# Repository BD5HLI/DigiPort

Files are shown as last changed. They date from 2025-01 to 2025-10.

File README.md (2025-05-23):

# 简介

面向八重洲FT-891的FT8模式集成接口，内置一个2口的USB2.0 HUB和一个USB声卡，通过一个Type-C接口连接电脑或者手机，解决FT-891没有内置声卡的问题。

本项目采用了Digirig-Mobile项目（https://github.com/softcomplex/Digirig-Mobile ）的符号库、封装库和3D器件模型，参考了Digirig DR-891的原理图（https://digirig.net/digirig-dr-891-setup-manual/ ）设计，精简了几乎用不到的CM108B GPIO脚的PTT功能，保留了VOX-PTT功能。此外，本项目的被动器件（电阻、电容）均采用0402手焊封装，便于手工焊接。

本项目虽然面向FT-891设计，实际上可以仅使用USB声卡的功能，从而适用于绝大多数带有音频输入输出接口的电台，比如K5、K6手台，配合相应的软件可以实现SSTV、APRS等玩法。

# 电路板渲染图

电路板正面：

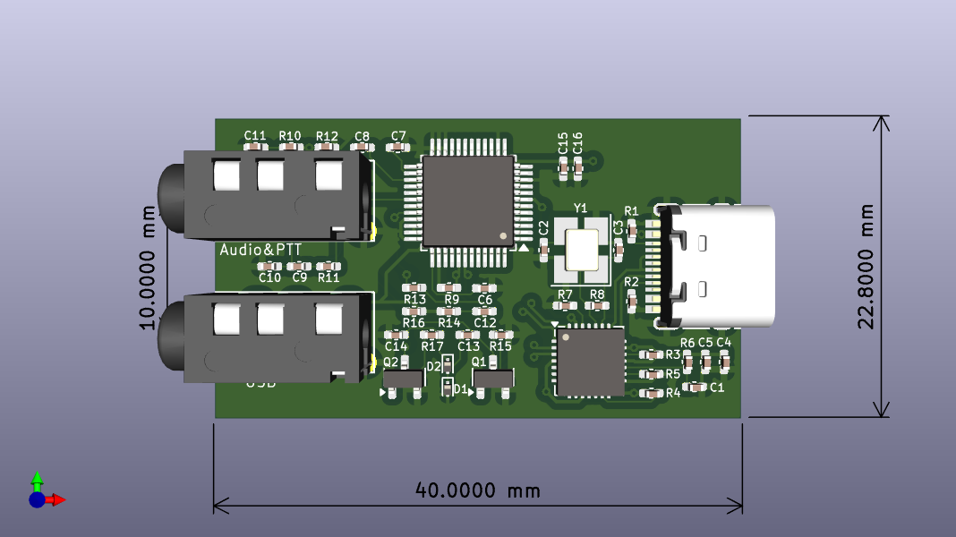
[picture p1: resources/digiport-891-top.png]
电路板正面


电路板反面：

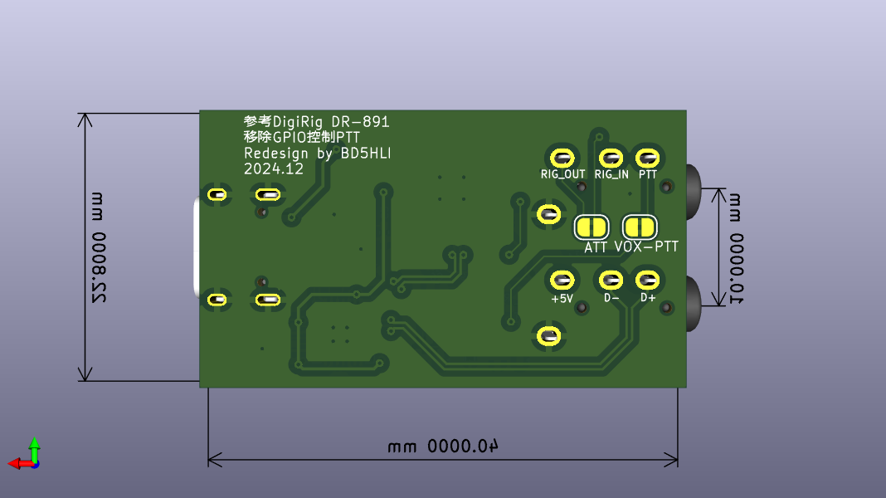
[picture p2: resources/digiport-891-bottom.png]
电路板反面


# 接口

DigiPort在电脑侧的接口为type c接口，可使用c to a或c to c数据线连接电脑或者手机；在电台侧的接口包括两个3.5mm的4芯TRRS接口，面向电路板器件面、type c接口在右侧时，左上的TRRS接口为音频/PTT接口，左下的TRRS接口为USB接口。

DigiPort的音频/PTT接口定义如下：  

```
   /\  
  |  |---------> 尖端   RIG_AFOUT 电台音频输出，接FT-891 DATA口的DATA OUT脚  
  |--|  
  |  |---------> 第一环 RIG_AFIN  电台音频输入，接FT-891 DATA口的DATA IN脚  
  |--|  
  |  |---------> 第二环 VOX_PTT   声控PTT，接FT-891 DATA口的PTT脚  
  |--|  
  |  |---------> 底部   GND       信号地，接FT-891 DATA口的GND脚  
__|  |__
|      |  
```

VOX_PTT信号用于没有USB串口的设备控制收发转换，控制源来自CM108B声卡的右声道，推荐采用1kHz或2kHz的单音作为VOX触发信号。

FT-891的DATA**插座**定义如下：

```
    /-----\      1脚：DATA IN  
   / 6 _ 5 \     2脚：GND  
  |4  |_|  3|    3脚：PTT  
   \ 2   1 /     4脚：SHIFT  
    \-----/      5脚：DATA OUT   
                 6脚：SQL   
```

DigiPort的电台侧USB接口定义如下：  

```
   /\  
  |  |---------> 尖端   +5V 电台USB口的+5V电源脚  
  |--|  
  |  |---------> 第一环 D-  电台USB口的D-脚  
  |--|  
  |  |---------> 第二环 D+  电台USB口的D+脚  
  |--|  
  |  |---------> 底部   GND 电台USB口的GND脚  
__|  |__  
|      |  
```

USB Type-B**插头**定义如下：

```
   /-+=+--+=+-\     1脚：+5V     
  /  |=|  |=|  \        
  |   1    2   |    2脚：D-  
  |            |   
  |   4    3   |    3脚：D+  
  |  |=|  |=|  |   
  |--+=+--+=+--|    4脚：GND  
```

# 各目录内容说明

- digiport-891目录下是kicad格式的原理图和PCB图。  
- endboard目录下是采用25mm * 25mm * 40mm对扣小铝壳的端板3D图纸。  
- 3D-models目录下是部分器件的3D模型，来自Digirig-Mobile项目。  
- footprints.pretty目录下是部分器件的封装库，来自Digirig-Mobile项目。  
- symbols目录下是部分器件的符号库，来自Digirig-Mobile项目。  

# 致谢

- 感谢LX6FB提供原版DR-891的照片。

- 感谢BG5ARO对端板设计提出了宝贵建议，并提供了CNC加工。

- 感谢BG5BQB提供了3D打印工艺的端板原型样件。

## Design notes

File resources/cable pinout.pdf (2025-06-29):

Part 1: Cables for YAESU Transceivers

Cable 1.1-Audio and PTT connect for YAESU radios

mini din 6pin male | 3.5mm 4pin male
| 1-DATA IN | R1-DATA IN
| 2-GND | G-GND
| 3-PTT | R2-PTT
| 5-DATA OUT | T-DATA OUT

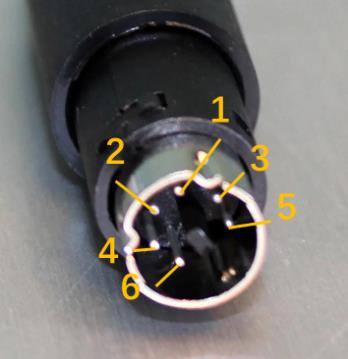
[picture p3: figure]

Cable 1.2-USB connect for FT-891

usb type-b plug | 3.5mm 4pin male
| 1-Vcc | T-Vcc
| 2-D- | R1-D-
| 3-D+ | R2-D+
| 4-GND | G-GND

Cable 1.3-CAT connect for FT-817/818/857/897

mini din 8pin male | 3.5mm 4pin male
| 4-TxD | T-TxD
| 5-RxD | R1-RxD
| 3-GND | R2&G-GND

Part 2: Cables for ICOM Transceivers

Cable 2.1-Audio and PTT connect for ICOM radios

din 13pin male | 3.5mm 4pin male
| 2-GND | G-GND
| 3-HSEND | R2-PTT
| 11-MOD | R1-DATA IN
| 12-AF | T-DATA OUT
| 10-FSKK | CI-V connector R2 pin

Cable 2.2-CI-V connect for ICOM radios

3.5mm 2pin male | 3.5mm 4pin male
| T-CI-V | T-CI-V
| | R1-NC
| | R2-NC or FSKK
| G-GND | G-GND

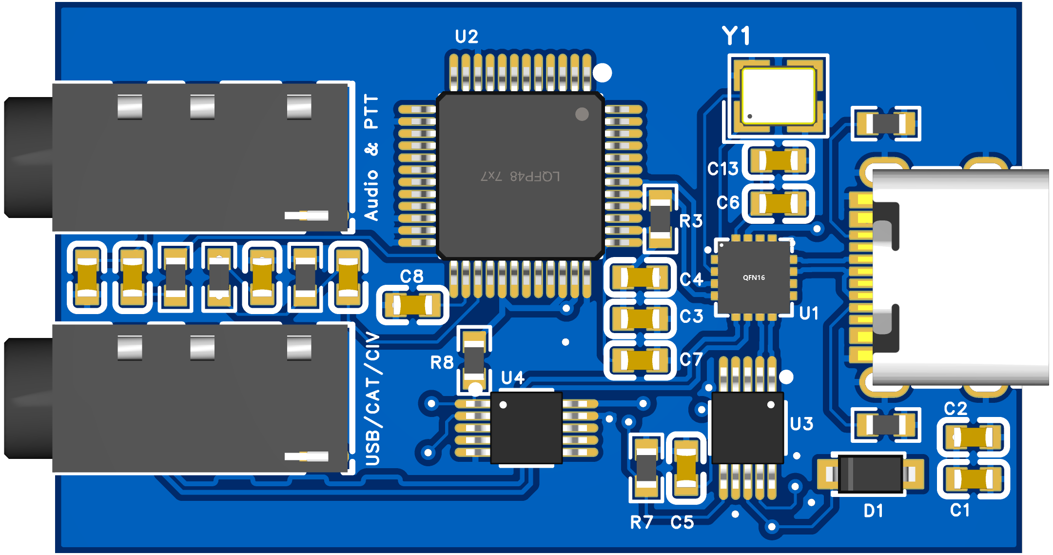
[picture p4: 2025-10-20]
resources/digiport-gerneral-top.png

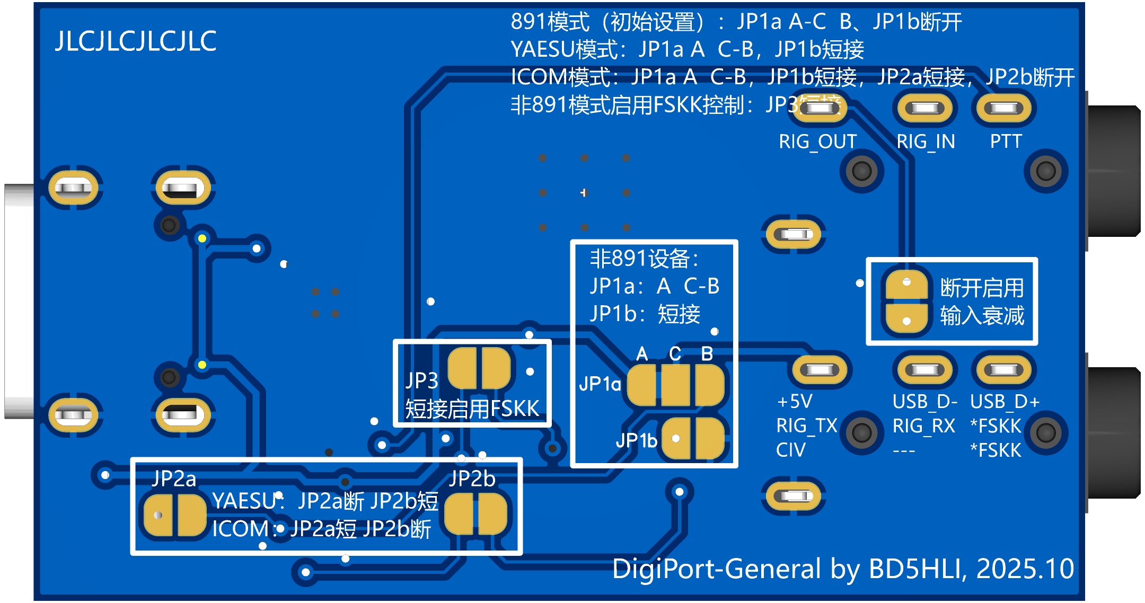
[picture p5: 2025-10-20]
resources/digiport-gerneral-bottom.png

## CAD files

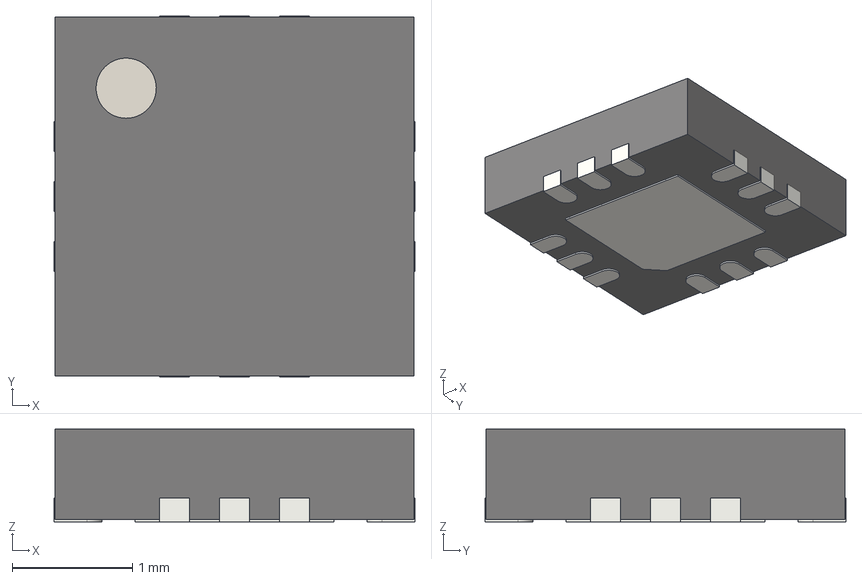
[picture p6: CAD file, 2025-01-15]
3d-models/QFN-12-1EP_3x3mm_P0.5mm_EP1.65x1.65mm.step
3.00 x 3.00 x 0.77 mm

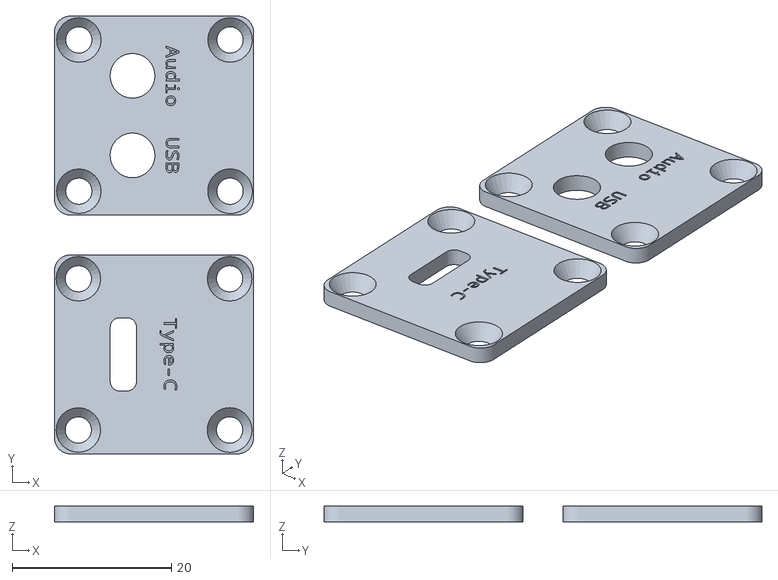
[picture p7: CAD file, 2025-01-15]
endboard/DigiPort-891.stl
25.0 x 55.0 x 2.00

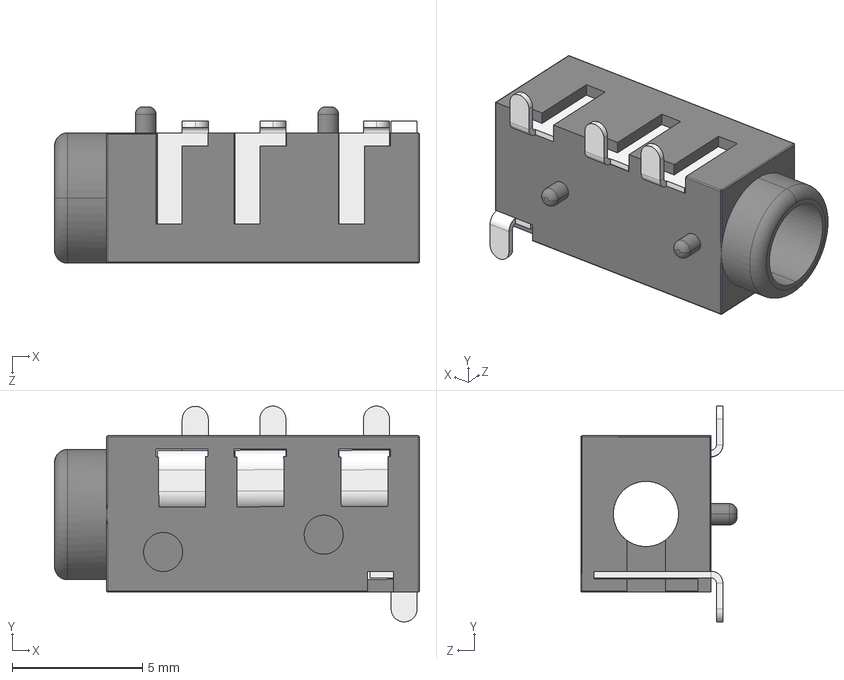
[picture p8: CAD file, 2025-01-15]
3d-models/PJ320D.STEP
14.0 x 8.28 x 6.00 mm
PJ320A
PJ320D-Pin x 3
PJ320D-Pin-B

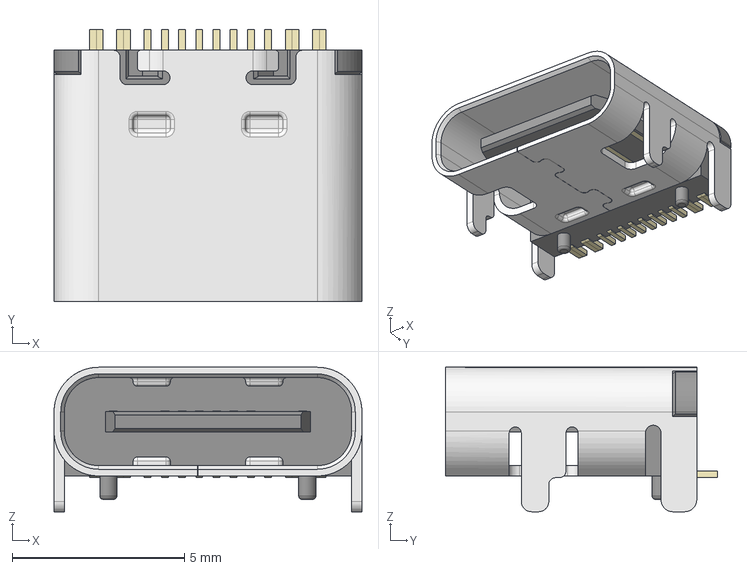
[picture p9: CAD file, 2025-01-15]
3d-models/HRO_TYPE-C-31-M-12.step
8.95 x 7.90 x 4.20 mm

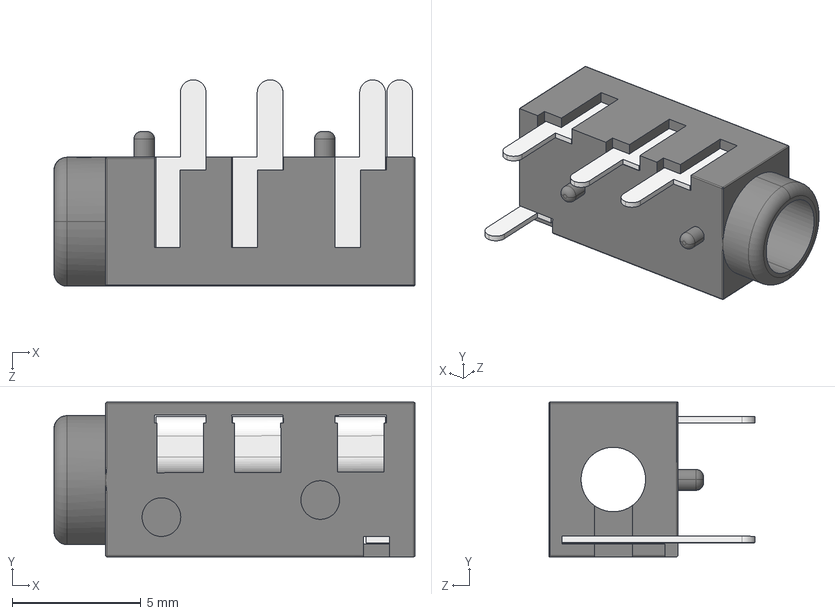
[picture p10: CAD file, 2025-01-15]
3d-models/PJ320A.STEP
14.0 x 6.00 x 8.00 mm
PJ320A
PJ320A-Pin x 3
PJ320A-Pin-B

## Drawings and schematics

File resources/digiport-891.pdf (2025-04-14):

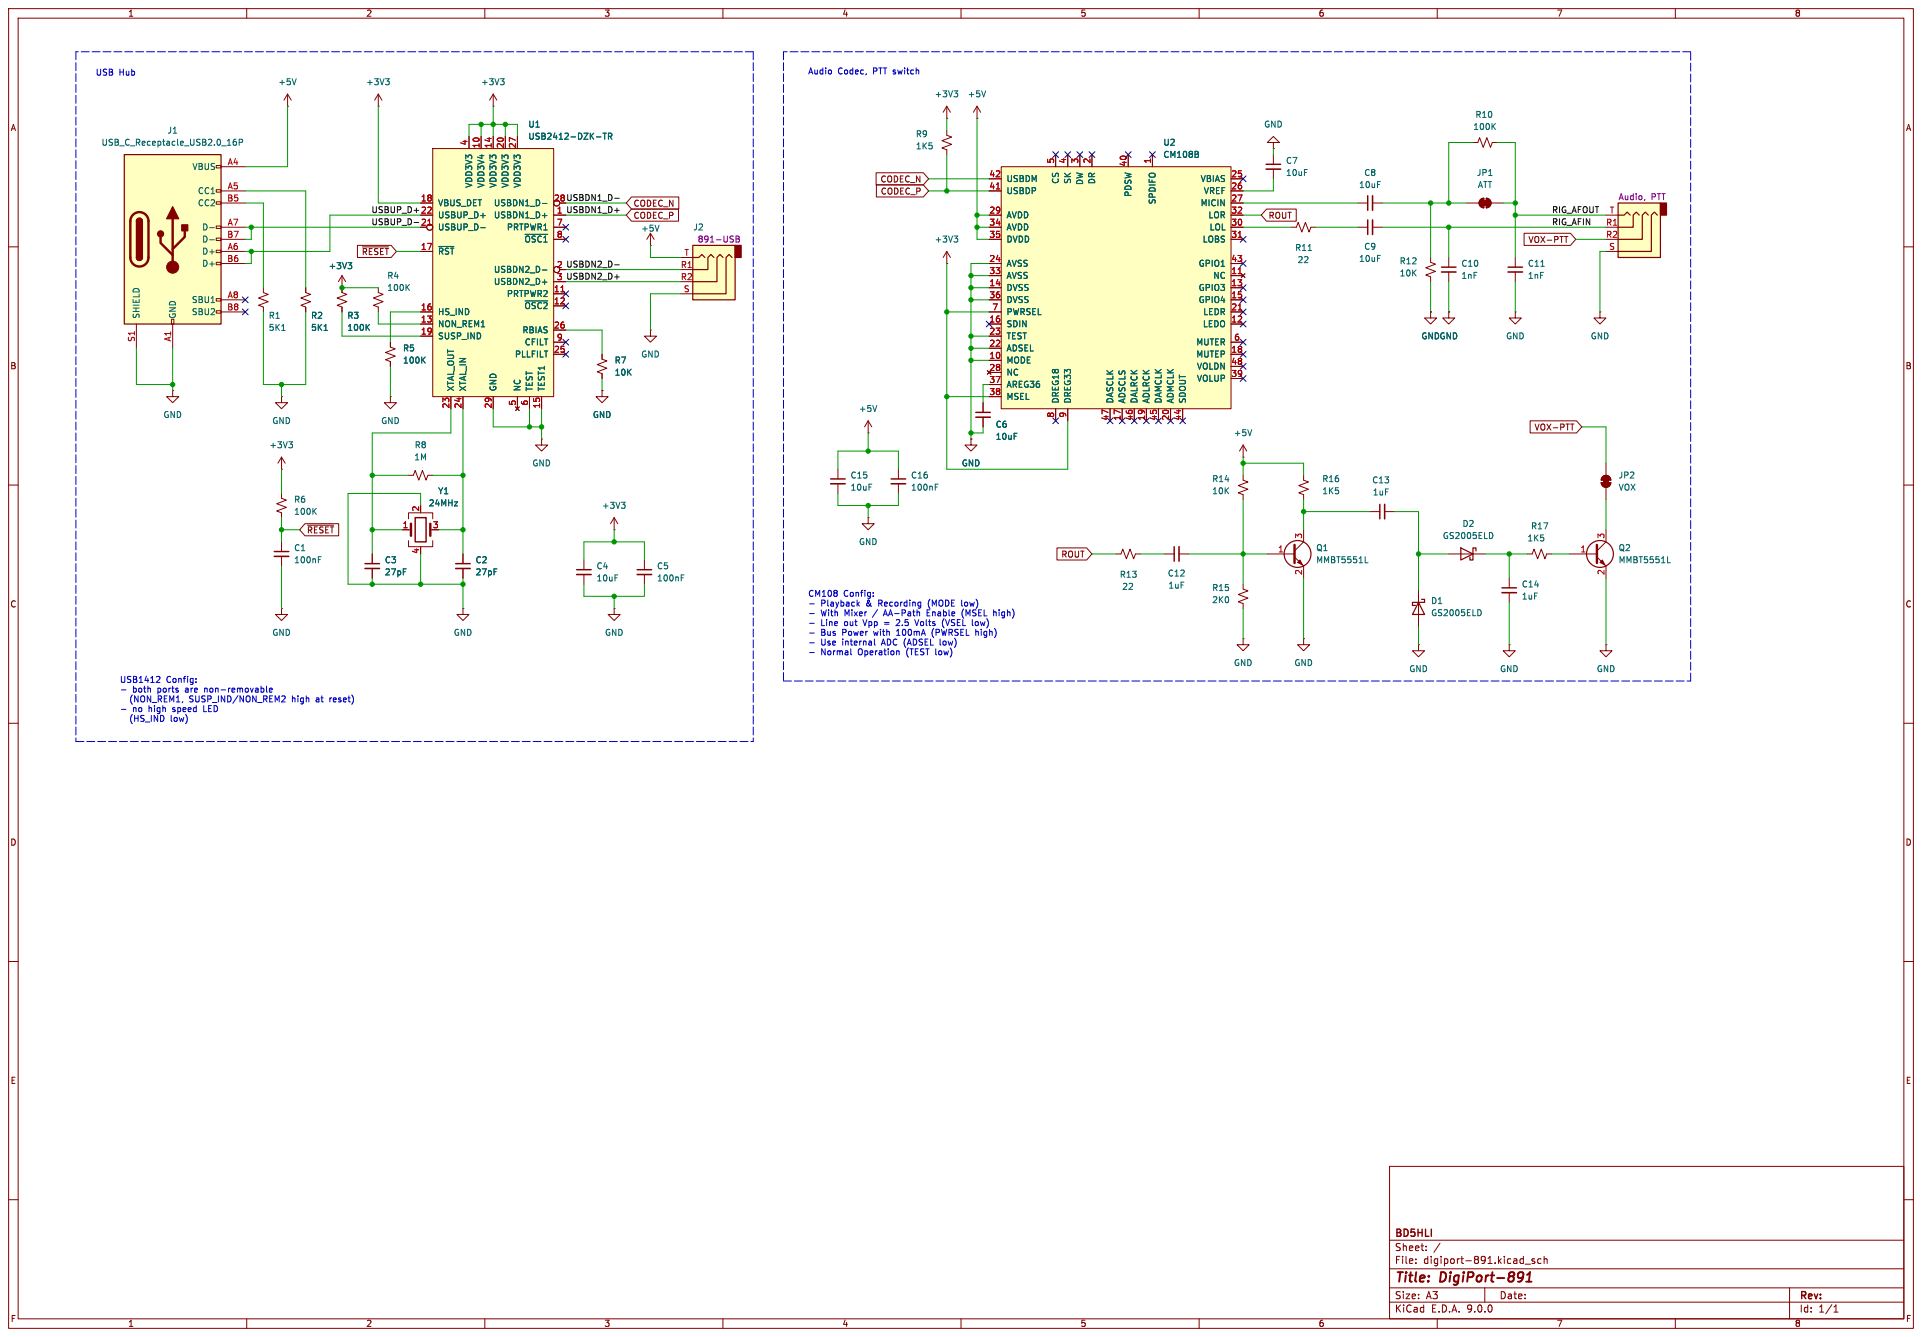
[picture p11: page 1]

6 TEST1 15 USBDN1_D- 28 USBDN1_D+ 1 PRTPWR1 7 ~{OSC1}8 USBDN2_D- 2 USBDN2_D+ 3 PRTPWR2 11 ~{OSC2}12 RBIAS 26 CFILT 9 PLLFILT 25 U1 USB2412-DZK-TR

2 DASCLK 47 ADSCLS 17 PDSW 40 DALRCK 46 ADLRCK 19 SPDIFO

1 DAMCLK 45 ADMCLK 20 SDOUT 44 VBIAS 25 VREF 26 MICIN 27

- Line out Vpp = 2.5 Volts (VSEL low)
- Bus Power with 100mA (PWRSEL high)

- no high speed LED

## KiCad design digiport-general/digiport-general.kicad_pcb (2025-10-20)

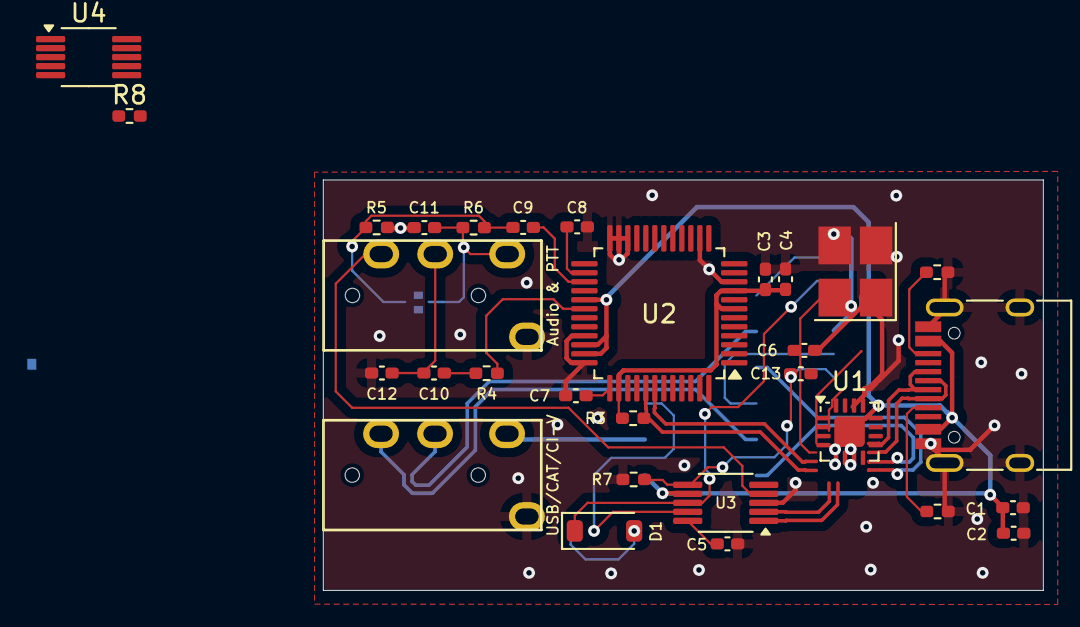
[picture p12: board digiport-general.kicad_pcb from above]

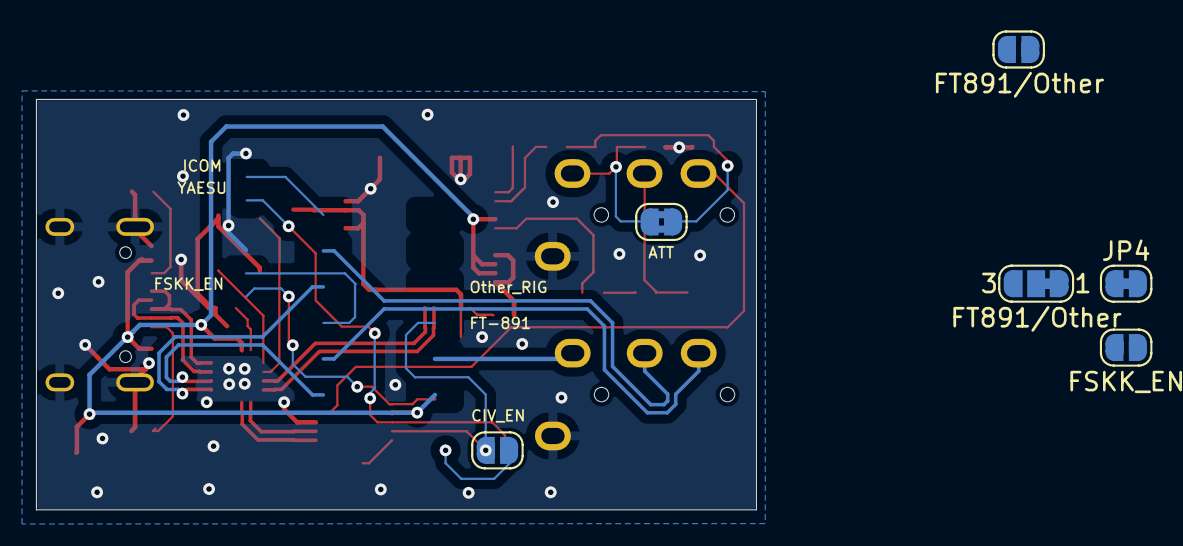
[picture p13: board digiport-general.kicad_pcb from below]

Board: 2 copper layers, 40.0 x 22.8 mm, 36 parts (2 on the bottom side), 35 nets.

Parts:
C1, C3, C6, C7, C8, C9, C10: 10uF; C_0402_1005Metric_Pad0.74x0.62mm_HandSolder
C2, C4, C5, C13: 100nF; C_0402_1005Metric_Pad0.74x0.62mm_HandSolder
C11, C12: 1nF; C_0402_1005Metric_Pad0.74x0.62mm_HandSolder
D1: 1N4148W; D_SOD-123
J1: Audio&PTT; TRRS-PJ-320A
J2: USB/CIV/CAT; TRRS-PJ-320A
J3: USB_C_Receptacle_USB2.0_16P; USB_C_Receptacle_HRO_TYPE-C-31-M-12
JP1: FT891/Other; SolderJumper2-BCu
JP2: FT891/Other; SolderJumper3-BCu
JP3: CIV_EN; SolderJumper-2_P1.3mm_Open_RoundedPad1.0x1.5mm
JP4: Yaesu/ICOM; SolderJumper-BCu-Bridged
JP5: FSKK_EN; SolderJumper2-BCu
JP6: ATT; SolderJumper-2_P1.3mm_Bridged2Bar_RoundedPad1.0x1.5mm
R1, R2: 5.1k; R_0402_1005Metric_Pad0.72x0.64mm_HandSolder
R3: 1.5k; R_0402_1005Metric_Pad0.72x0.64mm_HandSolder
R4: 22; R_0402_1005Metric_Pad0.72x0.64mm_HandSolder
R5, R8: 10k; R_0402_1005Metric_Pad0.72x0.64mm_HandSolder
R6: 100k; R_0402_1005Metric_Pad0.72x0.64mm_HandSolder
R7: 4.7k; R_0402_1005Metric_Pad0.72x0.64mm_HandSolder
U1: CH334P; QFN-16-1EP_3x3mm_P0.5mm_EP1.7x1.7mm_ThermalVias
U2: CM108B; LQFP-48_7x7mm_P0.5mm
U3: CH340X; MSOP-10_3x3mm_P0.5mm
U4: CH442E; MSOP-10_3x3mm_P0.5mm
Y1: 12MHz; Crystal_SMD_3225-4Pin_3.2x2.5mm_HandSoldering

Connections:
891USB_D+: U1.6 (DP3+), U4.7 (S2C)
891USB_D-: U1.5 (DM3-), U4.3 (S2B)
+3.3V: C3.1, C4.1, R3.1, U2.7 (PWRSEL), U2.9 (DREG33), U2.38 (MSEL)
+5V: C1.1, C2.1, J3.A4 (VBUS), J3.A9 (VBUS), J3.B4 (VBUS), J3.B9 (VBUS), JP2.1 (A), R8.1, U1.15 (V5), U2.29 (AVDD), U2.34 (AVDD), U2.35 (DVDD), U3.7 (VCC), U4.10 (VCC)
/DU+: J3.A6 (D+), J3.B6 (D+), U1.12 (DPU+)
/DU-: J3.A7 (D-), J3.B7 (D-), U1.11 (DMU-)
/RIG_AFIN: C10.1, C12.1, J1.R1
/RIG_AUOUT: C11.1, J1.T, JP6.2 (B), R6.2
AUDIO_D+: R3.2, U1.4 (DP4+), U2.41 (USBDP)
AUDIO_D-: U1.3 (DM4-), U2.42 (USBDM)
GND: C1.2, C2.2, C3.2, C4.2, C5.2, C6.1, C7.2, C8.1, C11.2, C12.2, C13.1, J1.S, J2.S, J3.A1 (GND), J3.A12 (GND), J3.B1 (GND), J3.B12 (GND), J3.S1 (SHIELD), JP1.1 (A), R1.2, R2.2, R5.1, R7.2, U1.17 (GND), U2.10 (MODE), U2.14 (DVSS), U2.22 (ADSEL), U2.23 (TEST), U2.24 (AVSS), U2.33 (AVSS), U2.36 (DVSS), U3.3 (GND), U4.5 (GND), U4.9 (EN#), Y1.2, Y1.4
unnamed: C10.2, R4.2
unnamed: D1.2 (A), JP3.2 (B)
unnamed: J3.A5 (CC1), R2.1
unnamed: J3.B5 (CC2), R1.1
unnamed: JP1.2 (B), R8.2, U4.1 (IN)
unnamed: C9.1, JP6.1 (A), R5.2, R6.1
unnamed: C6.2, C13.2, U1.16 (VDD33)
unnamed: U1.2 (XI), Y1.3
unnamed: U1.1 (XO), Y1.1
unnamed: C7.1, U2.37 (AREG36)
unnamed: R4.1, U2.30 (LOL)
unnamed: C9.2, U2.27 (MICIN)
unnamed: C8.2, U2.26 (VREF)
unnamed: C5.1, U3.10 (V3)
PC_DTR: JP5.1 (A), R7.1, U3.6 (TNOW/~DTR)
PC_RTS: J1.R2, U3.4 (~RTS)
PC_RxD: JP2.3 (B), JP3.1 (A), U3.9 (RXD)
PC_TxD: D1.1 (K), JP4.1 (A), U3.8 (TXD)
RIGD_R+: J2.R2, U4.6 (DC)
RIGD_R-: J2.R1, U4.4 (DB)
RIGD_T: J2.T, JP2.2 (C)
RIG_RX: JP4.2 (B), U4.2 (S1B)
SERIAL_D+: U1.8 (DP2+), U3.1 (UD+)
SERIAL_D-: U1.7 (DM2-), U3.2 (UD-)

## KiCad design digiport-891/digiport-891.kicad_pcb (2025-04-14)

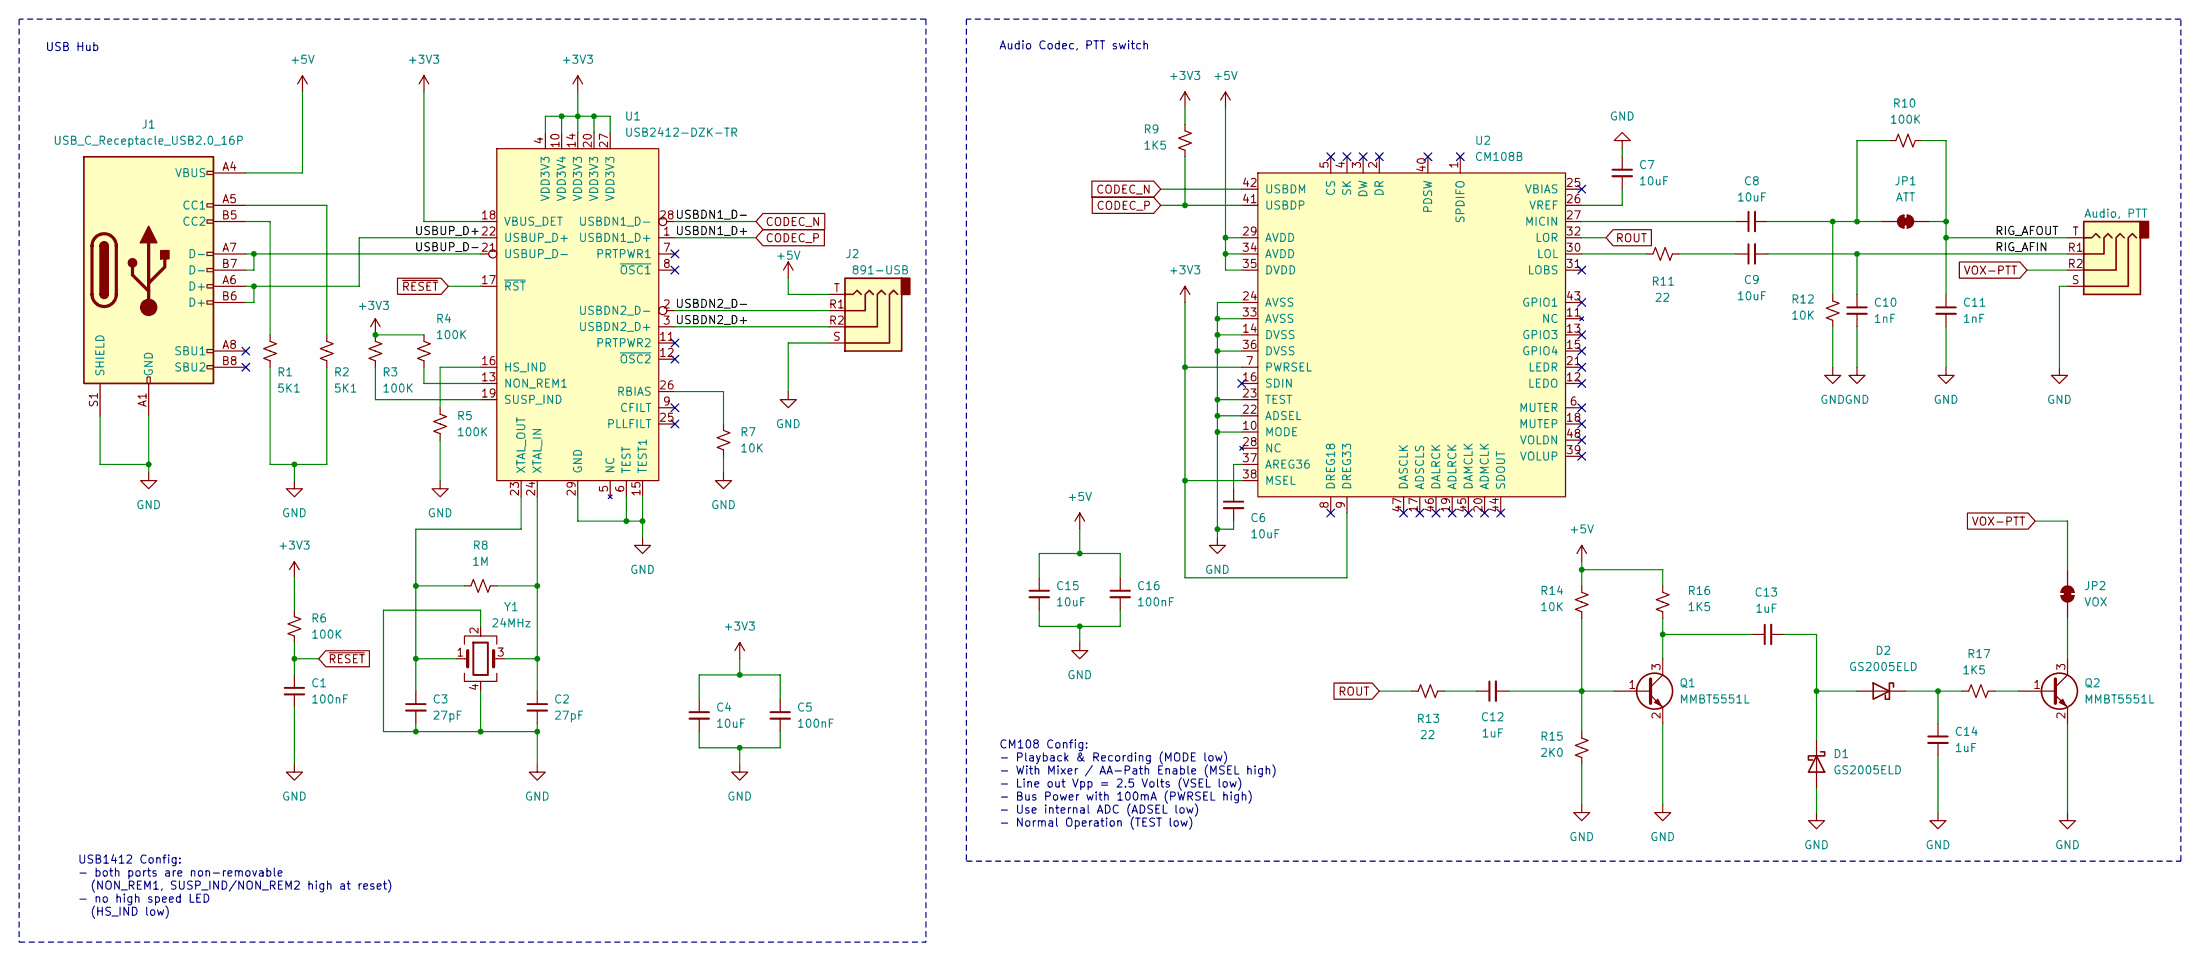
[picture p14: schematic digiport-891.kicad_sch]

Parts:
C1, C5, C16: 100nF; C_0402_1005Metric_Pad0.74x0.62mm_HandSolder
C2, C3: 27pF; C_0402_1005Metric_Pad0.74x0.62mm_HandSolder
C4, C6, C7, C8, C9, C15: 10uF; C_0402_1005Metric_Pad0.74x0.62mm_HandSolder
C10, C11: 1nF; C_0402_1005Metric_Pad0.74x0.62mm_HandSolder
C12, C13, C14: 1uF; C_0402_1005Metric_Pad0.74x0.62mm_HandSolder
D1, D2: GS2005ELD; D_SOD-923
J1: USB_C_Receptacle_USB2.0_16P; USB_C_Receptacle_HRO_TYPE-C-31-M-12
J2, J3: PJ-320A; TRRS-PJ-320A
JP1: ATT; SolderJumper-2_P1.3mm_Bridged2Bar_RoundedPad1.0x1.5mm
JP2: VOX; SolderJumper-2_P1.3mm_Bridged2Bar_RoundedPad1.0x1.5mm
Q1, Q2: MMBT5551L; SOT-23
R1, R2: 5K1; C_0402_1005Metric_Pad0.74x0.62mm_HandSolder
R3, R4, R5, R6, R10: 100K; C_0402_1005Metric_Pad0.74x0.62mm_HandSolder
R7, R12, R14: 10K; C_0402_1005Metric_Pad0.74x0.62mm_HandSolder
R8: 1M; C_0402_1005Metric_Pad0.74x0.62mm_HandSolder
R9, R16, R17: 1K5; C_0402_1005Metric_Pad0.74x0.62mm_HandSolder
R11, R13: 22; C_0402_1005Metric_Pad0.74x0.62mm_HandSolder
R15: 2K0; C_0402_1005Metric_Pad0.74x0.62mm_HandSolder
U1: USB2412-DZK-TR; QFN-28-1EP_5x5mm_P0.5mm_EP3.35x3.35mm
U2: CM108B; LQFP-48_7x7mm_P0.5mm
Y1: 24MHz; Crystal_SMD_3225-4Pin_3.2x2.5mm_HandSoldering

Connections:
+3V3: C4.1, C5.1, R3.1, R4.1, R6.1, R9.1, U1.4 (VDD3V3), U1.10 (VDD3V4), U1.14 (VDD3V3), U1.18 (VBUS_DET), U1.20 (VDD3V3), U1.27 (VDD3V3), U2.7 (PWRSEL), U2.9 (DREG33), U2.38 (MSEL)
+5V: C15.1, C16.1, J1.A4 (VBUS), J1.A9 (VBUS), J1.B4 (VBUS), J1.B9 (VBUS), J2.T, R14.1, R16.1, U2.29 (AVDD), U2.34 (AVDD), U2.35 (DVDD)
/RIG_AFIN: C9.2, C10.1, J3.R1
/RIG_AFOUT: C11.1, J3.T, JP1.2 (B), R10.2
/USBDN2_D+: J2.R2, U1.3 (USBDN2_D+)
/USBDN2_D-: J2.R1, U1.2 (USBDN2_D-)
/USBUP_D+: J1.A6 (D+), J1.B6 (D+), U1.22 (USBUP_D+)
/USBUP_D-: J1.A7 (D-), J1.B7 (D-), U1.21 (USBUP_D-)
CODEC_N: U1.28 (USBDN1_D-), U2.42 (USBDM)
CODEC_P: R9.2, U1.1 (USBDN1_D+), U2.41 (USBDP)
GND: C1.2, C2.2, C3.2, C4.2, C5.2, C6.2, C7.1, C10.2, C11.2, C14.2, C15.2, C16.2, D1.2 (A), J1.A1 (GND), J1.A12 (GND), J1.B1 (GND), J1.B12 (GND), J1.S1 (SHIELD), J2.S, J3.S, Q1.2 (E), Q2.2 (E), R1.2, R2.2, R5.2, R7.2, R12.2, R15.2, U1.6 (TEST), U1.15 (TEST1), U1.29 (GND), U2.10 (MODE), U2.14 (DVSS), U2.22 (ADSEL), U2.23 (TEST), U2.24 (AVSS), U2.33 (AVSS), U2.36 (DVSS), Y1.2, Y1.4
unnamed: C9.1, R11.2
unnamed: C12.1, R13.2
unnamed: C13.2, D1.1 (K), D2.2 (A)
unnamed: C14.1, D2.1 (K), R17.1
unnamed: J1.A5 (CC1), R2.1
unnamed: J1.B5 (CC2), R1.1
unnamed: C8.2, JP1.1 (A), R10.1, R12.1
unnamed: JP2.2 (B), Q2.3 (C)
unnamed: C12.2, Q1.1 (B), R14.2, R15.1
unnamed: C13.1, Q1.3 (C), R16.2
unnamed: Q2.1 (B), R17.2
unnamed: R5.1, U1.16 (HS_IND)
unnamed: R4.2, U1.13 (NON_REM1)
unnamed: R7.1, U1.26 (RBIAS)
unnamed: R3.2, U1.19 (SUSP_IND)
unnamed: C2.1, R8.1, U1.24 (XTAL_IN), Y1.3
unnamed: C3.1, R8.2, U1.23 (XTAL_OUT), Y1.1
unnamed: C6.1, U2.37 (AREG36)
unnamed: R11.1, U2.30 (LOL)
unnamed: C8.1, U2.27 (MICIN)
unnamed: C7.2, U2.26 (VREF)
ROUT: R13.1, U2.32 (LOR)
VOX-PTT: J3.R2, JP2.1 (A)
~RESET: C1.1, R6.2, U1.17 (~RST)

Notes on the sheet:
USB Hub
Audio Codec, PTT switch
CM108 Config: - Playback & Recording (MODE low) - With Mixer / AA-Path Enable (MSEL high) - Line out Vpp = 2.5 Volts (VSEL low) - Bus Power with 100mA (PWRSEL high) - Use internal ADC (ADSEL low) - Normal Operation (TEST low)
USB1412 Config: - both ports are non-removable (NON_REM1, SUSP_IND/NON_REM2 high at reset) - no high speed LED (HS_IND low)

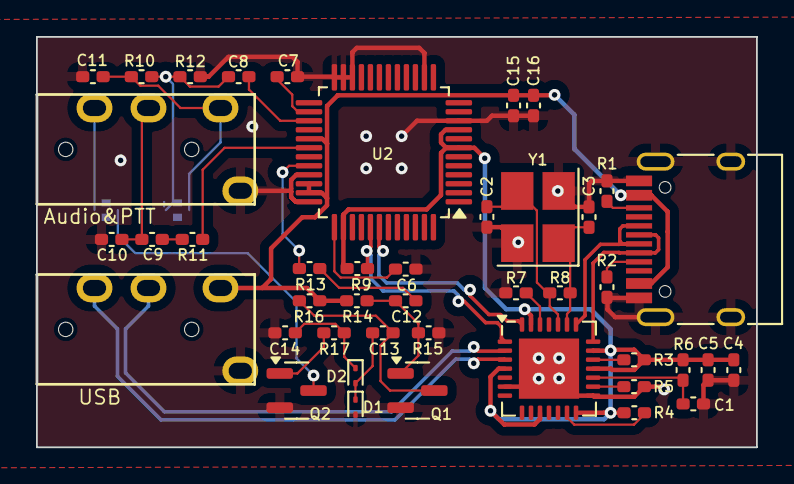
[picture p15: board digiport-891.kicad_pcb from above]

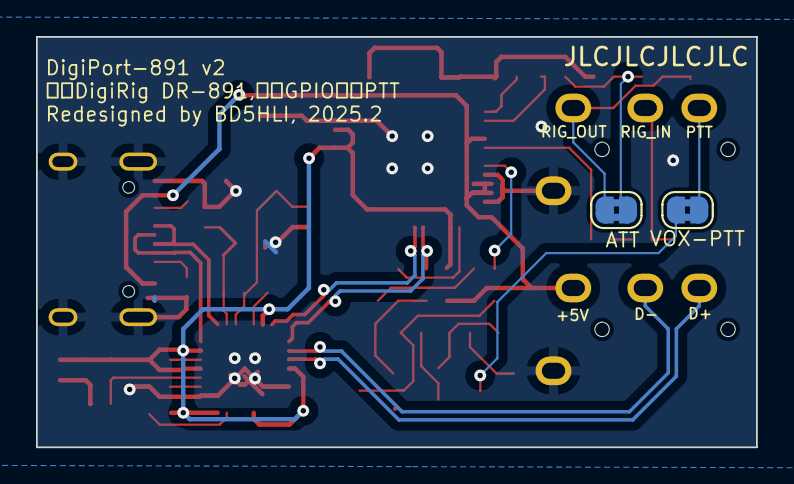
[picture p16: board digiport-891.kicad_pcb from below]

Board: 2 copper layers, 40.0 x 22.8 mm, 45 parts (2 on the bottom side), 35 nets.

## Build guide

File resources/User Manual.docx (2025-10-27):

业余电台数字模式接口盒子

DigiPort

用户手册

由BD5HLI设计

2025年10月

目 录

# 1 概览

## 1.2 注意事项

本产品带有1个USB Type C接口和2个四芯的3.5mm插口。其中Type C接口支持带电热插拔，而3.5mm插口不支持带电热插拔，插拔此接口时请务必关闭无线电台，并将USB Type C接口的电缆从本产品上拔出，以避免潜在的损坏风险。

与本产品对应的电台侧接口包括USB Type B接口、6芯mini DIN接口、8芯mini DIN接口、13芯DIN接口、2芯3.5mm接口等（依对接的电台型号不同而有所差异），除USB Type B接口外，上述其他接口均不支持带电热插拔，插拔这些接口时请务必关闭无线电台，并将USB Type C接口的电缆从本产品，以避免潜在的损坏风险。

## 1.3 功能概述

DigiPort是面向FT-891、FT-817/818、FT-857/897、IC-7000、IC-706等没有集成USB声卡的电台而开发的数据接口盒子。

DigiPort内部集成了USB HUB、USB串口和USB声卡，可以实现电台与上位机（PC、Mac或移动设备等）“一线通”连接运行FT8、APRS、SSTV、RTTY等模式。甚至通过制作专用电缆，可以作为Motorola SM50等电台的写频器使用。

与不同业余无线电台共同使用时的具体功能如下：

- 与YAESU FT-891电台共同使用时，仅需一根USB Type C就实现数据、音频双重连接，无需占用上位机的3.5mm音频接口。
- 与YAESU FT-817/818、FT-857/897等电台共同使用时，仅需一根USB Type C就实现CAT控制、收发音频双重连接，为老电台提供现代化的连接能力。还可以通过启用FSKK引脚，配合专用连接电缆实现FSK模式的RTTY通信或上位机发送CW等功能。
- 与ICOM IC-7000、IC-706等电台同使用时，仅需一根USB Type C就实现CI-V控制、收发音频双重连接，为老电台提供现代化的连接能力。还可以通过启用FSKK引脚，配合专用连接电缆实现FSK模式的RTTY通信或上位机发送CW等功能。

## 1.4 包装内容

本产品包装内包括以下物品：

- DigiPort本体 1只
- USB Type C to Type C电缆 1条
- 六芯mini DIN音频及PTT电缆 1条¹ ²
- USB Type B控制电缆 1条¹
- 八芯mini DIN控制电缆 1条²
- 二芯3.5mm控制电缆 1条³
- 十三芯DIN音频及PTT电缆 1条³
- 磁环（已安装在电缆上）

注：1、与FT-891机型适配

2、与FT-817/818、FT-857/897机型适配

3、与IC-7000、IC-706机型适配

本包装内包括的控制电缆和音频电缆的数量和类型依购买时提出的需求可能会有所不同。

## 1.5 面板描述

USB Type C面板：

用于连接上位机（PC、Mac、移动设备等）

控制/音频面板：

音频接口：连接音频及PTT电缆，用于音频输入输出以及PTT控制

控制接口：连接控制电缆，用于DigiPort与电台的USB Type B或CAT/CI-V接口通信并传输可选的FSKK信号

# 3 与Yaesu FT-891共同使用

## 3.1 将FT-891与上位机连接

按以下顺序将FT-891通过DigiPort与上位机连接：

1. 关闭FT-891电源。
2. 将音频电缆的6芯mini DIN插头插入FT-891后部的DATA接口（如图2.1a），连接时注意插头方向，以免损坏插针；然后将音频电缆另一端的3.5mm插头插入DigiPort的音频接口。
3. 将控制电缆的USB Type B插头插入FT-891后部的USB Type B接口（如图2.1b）；然后将控制电缆另一端的3.5mm插头插入DigiPort的控制接口。
4. 将DigiPort的USB Type C接口与上位机连接。
5. 开启FT-891电源。

## 3.2 FT-891的设置

为了发挥DigiPort的功能，需要在FT-891电台上进行如下设置：

1. CAT设置
2. 信号源设置，在xx号菜单中将信号源设置为REAR；
3. 滤波器设置
4. 数据模式设置

## 3.3 上位机的设置

为了发挥DigiPort的功能，需要在上位机上进行必要的设置。以Windows 11平台JTDX软件运行FT8模式为例，具体的设置内容如下：

1. Windows系统音频设备设置
2. JTDX软件音频设备选择
3. JTDX软件CAT设置

# 4 与其他Yaesu电台共同使用

以FT-817ND为例

## 4.2 将电台与上位机连接

由于FT-817/818、FT-857/897等其他Yaesu电台在音频接口和CAT接口方面具有较高的相似性，本手册以FT-817ND为例进行介绍。

按以下顺序将FT-817ND通过DigiPort与上位机连接：

1. 关闭FT-817ND电源。
2. 将音频电缆的6芯mini DIN插头插入FT-817ND后部的DATA接口（如图3.1a），连接时注意插头方向，以免损坏插针；然后将音频电缆另一端的3.5mm插头插入DigiPort的音频接口。
3. 将控制电缆的8芯mini DIN插头插入FT-817ND后部的TUN/LIN接口（如图3.1b）；然后将控制电缆另一端的3.5mm插头插入DigiPort的控制接口。
4. DigiPort的USB Type C接口与上位机连接。
5. 开启FT-817ND电源。

## 4.3 电台的设置

为了发挥DigiPort的功能，需要在FT-817ND电台上进行如下设置：

1. CAT设置
2. 信号源设置，在xx号菜单中将信号源设置为REAR；
3. 滤波器设置
4. 数据模式设置

## 4.4 上位机的设置

DigiPort与FT-817ND电台共同使用时，上位机的设置与FT-891类似，具体内容请参考2.2节。

## 4.5 使用FSK Key功能

# 5 与ICOM电台共同使用

## 5.1 将电台与上位机连接

由于IC-7000、IC-706等ICOM电台在音频接口和CI-V接口方面具有较高的相似性，本手册以IC-7000为例进行介绍。

按以下顺序将IC-7000通过DigiPort与上位机连接：

1. 关闭IC-7000电源。
2. 将音频电缆的13芯DIN插头插入IC-7000后部的ACC接口（如图4.1a），连接时注意插头方向，以免损坏插针；然后将音频电缆另一端的3.5mm插头插入DigiPort的音频接口。
3. 将控制电缆的2芯3.5mm插头插入IC-7000后部的CI-V接口（如图4.1b）；然后将控制电缆另一端的3.5mm插头插入DigiPort的控制接口。
4. DigiPort的USB Type C接口与上位机连接。
5. 开启IC-7000电源。

## 5.2 电台的设置

## 5.3 上位机的设置

DigiPort与ICOM IC-7000电台共同使用时，上位机的设置与FT-891类似，具体内容请参考2.2节。

## 5.4 使用FSK Key功能

# 6 与其他电台共同使用

## 6.1 将电台与上位机连接

## 6.2 电台的设置

## 6.3 上位机的设置

## 6.4 使用FSK Key功能

# 7 故障诊断

## 7.1 电台无法切换收发状态

## 7.2 电台能切换收发状态但无输出功率

## 7.3 上位机无法控制电台切换频率

# 8 附录

## 8.1 在不同模式之间切换

## 8.2 启用和禁用可选的FSKK信号

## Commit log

2025-01-15 增加端板的3D模型STL文件
    [DigiPort-891.stl]
2025-01-15 renamed digirig-891 to digiport-891
    [digiport-891.kicad_pcb, digiport-891.kicad_sch]
2025-01-15 v2：优化PCB布局，将RIG_AFIN和RIG_AFOUT移动到音频接插件附近，减少过孔数量， 避免焊盘上的过孔。
    [digiport-891.kicad_pcb, digiport-891.kicad_sch]
2025-01-15 优化PCB布线
    [digiport-891.kicad_pcb]
2025-02-11 add PNG of pcb and PDF of shcematic
    1. PNG of PCB and PDF of schematic are added
    2. Library path is changed to relative path.
    [digiport-891.kicad_pcb, digiport-891.kicad_sch]
2025-03-10 cable pinout file added
    [digiport-891.kicad_pcb, digiport-891.kicad_sch]
2025-04-14 C12 value corrected.
    [digiport-891.kicad_pcb, digiport-891.kicad_sch]
2025-05-23 DigiPort-General version is added
    [digiport-general.kicad_sch]
2025-06-29 digiport-gerneral bug fixed, update cable pinout document
    [digiport-general.kicad_sch]
2025-10-20 DigiPort-General v2 is added
    [digiport-general.kicad_pcb]
2025-10-20 Delete cable pinout.pdf
    Delete \cable pinout.pdf

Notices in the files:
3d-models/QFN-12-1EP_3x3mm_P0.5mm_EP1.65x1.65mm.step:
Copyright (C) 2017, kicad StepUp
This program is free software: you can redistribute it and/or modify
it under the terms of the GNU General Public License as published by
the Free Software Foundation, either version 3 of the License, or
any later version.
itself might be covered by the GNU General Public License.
